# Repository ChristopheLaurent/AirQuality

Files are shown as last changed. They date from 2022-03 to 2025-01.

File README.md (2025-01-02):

# AirQuality

The purpose of this project is indoor air quality monitoring with affordable IoT devices. It covers all aspects of the problem, from sensors to data monitoring, including 3D modeling, electronics, communication protocols, data base and web front end.

## IoT Device

The device displays CO2 level with a smiley depending on the CO2 level, so it can be used in standalone mode.



The device is based on 2 circuits, connected via I2C in a [3D printed casing](https://github.com/ChristopheLaurent/AirQuality/tree/main/Model3D):
### [Sensirion SCD41](https://developer.sensirion.com/sensirion-products/scd4x-co2-sensors/)
The SEK-SCD41-Sensor Evaluation Kit can measure CO2 level, Humidity and Temperature. It is powered in 3.3V. The sampling rate is 5s in normal mode, 30s in low power mode.
### [LILYGO® TTGO T5 V2.3.1_2.13](https://lilygo.cc/products/t5-v2-3-1)
This [ESP32 ECO V3](https://www.espressif.com/sites/default/files/documentation/ESP32_ECO_V3_User_Guide__EN.pdf) module integrates an e-Paper screen, SD card, USB, JSP plug for battery support, WiFi and Bluetooth. The JST plug can be connected to an optional 18650 lithium battery. The USB can be connected to a 5V/1A mobile phone power supply.

## Backend server

The devices can connect to a Flask server via WiFi / MQTT.



The Flask server can run on a PC, together with a mosquitto broker and PostgreSQL data base

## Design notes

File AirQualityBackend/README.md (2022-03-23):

# Backend

AirQuality backend is designed to run on a local WiFi network, not the cloud. It handles MQTT publications from sensors south bound, and Web request from browsers north bound. It stores all measures from sensors on a local PostGres data base.



## Windows Installation steps

### PostgreSQL
- [Install postgres DB](https://www.postgresql.org/download/windows/)
- You can use `admin` as password. (it is hardcoded in the source code for the time being)
- Do not launch stack builder at exit.
- Create database `AirQuality` (using pgAdmin for example)

### Mosquitto
- [Install Mosquitto broker](https://mosquitto.org/download/)
- If you choose to run mosquitto as a service, you can reboot your computer then check mosquitto.exe process is running.
- If you decide to run it manually, go to the mosquitto folder with a command prompt then type `mosquitto -v`

### Python
- [Install latest Python 3 version](https://www.python.org/downloads/)
- During installation process, ticks Add Python 3.xx to PATH

Run as admin windows power shell then type the following commands:
-	`cd AirQuality\AirQualityBackend`
-	`Set-ExecutionPolicy Unrestricted -Force`
-	`pip install virtualenv`
-	`virtualenv venv`
-	`venv\Scripts\activate`
-	`pip install Flask`
-	`pip install psycopg2`
-	`pip install flask-mqtt`
-	`python init_db.py`
-	`$env:FLASK_APP = "app"`
-	`flask run --host=0.0.0.0`
-	Open your favorite browser then go to [http://127.0.0.1:5000/raw](http://127.0.0.1:5000/raw). You should see an empty table:



-	In another power shell, execute `python twin.py` . This will run a digital twin that simulates a sensor to populate the data base. If you refresh your browser, you should then see some data:



- You can then navigate up to the graphics:



## Data model

The data base is designed to support the following features:
- Each sensor is identified by its serial number.
- Each sensor has a type (for example SCD41, but it could be something else).
- Each sensor type has a set of channels.
- Each channel is defined by a name (for example CO2) and a unit (for example ppm).
- Each channel has a set of measures, e.g. samples (time stamp and value).
- At a given period of time, a sensor is in a location.
- A location is identified by a building, floor, room number...



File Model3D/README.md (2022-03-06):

# Hardware

Making Air Quality sensor only requires a 3D printer and basic soldering skills. The components are listed below:
- [SEK-SCD41-Sensor Evaluation Kit](https://developer.sensirion.com/sensirion-products/scd4x-co2-sensors/)
- [LILYGO® TTGO T5 V2.3.1_2.13](http://www.lilygo.cn/prod_view.aspx?TypeId=50061&Id=1393&FId=t3:50061:3)
- 11 x M2 screws 3mm
- [18650 battery holder](https://fr.aliexpress.com/item/1005001660193629.html) - optional
- 2 x magnets N35 10 x 3mm - optional
- 18650 lithium battery - optional

## 3D printing

The casing can be printed in PLA or PETG. It is designed for printing **without support**. *To be completed*

## Soldering
*To be completed*

## Connections
*To be completed*

## Assembling

- Slide the [button](https://github.com/ChristopheLaurent/AirQuality/blob/main/Model3D/button.stl) in the [main box](https://github.com/ChristopheLaurent/AirQuality/blob/main/Model3D/main.stl).
- Fasten the SCD41 kit and the micro controler in the main box with 8 M2 screws.
- Push the magnets in the holes of the [back](https://github.com/ChristopheLaurent/AirQuality/blob/main/Model3D/back.stl).
- Fasten the 18650 battery holder with 1 M2 screw.
- Insert the 18650 battery. **Double check polarity**.
- Fasten the back to the main box with 2 M2 screws.

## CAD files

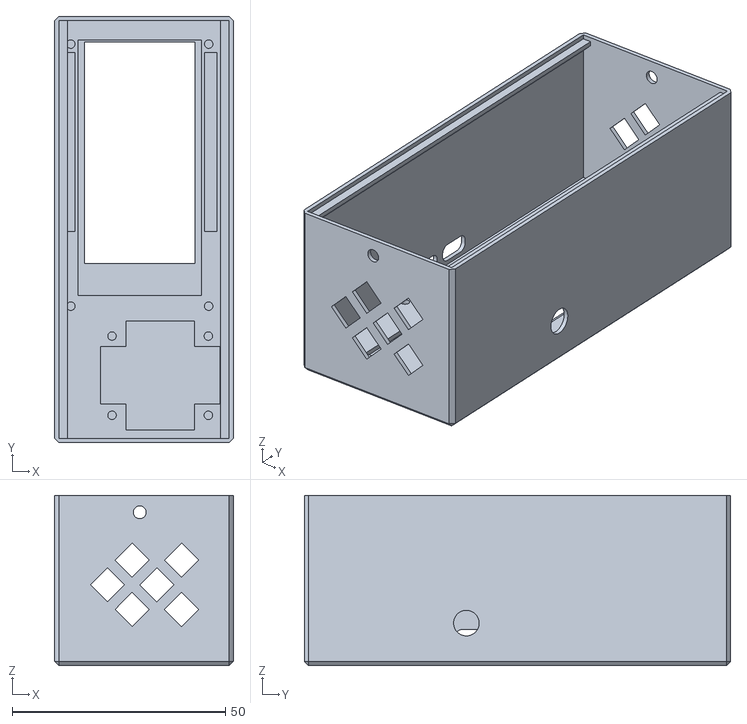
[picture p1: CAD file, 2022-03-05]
Model3D/main.stl
42.0 x 100.0 x 40.0

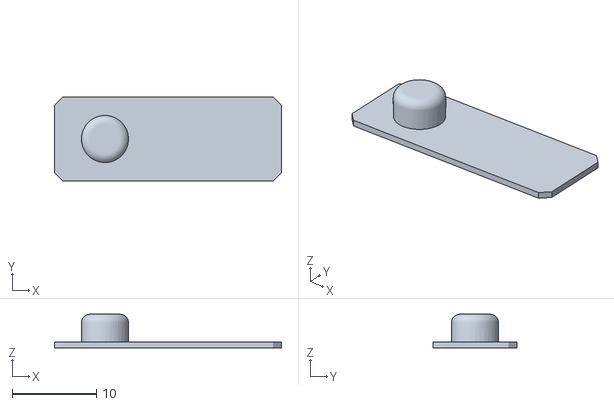
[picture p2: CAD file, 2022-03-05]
Model3D/button.stl
27.0 x 10.0 x 4.00

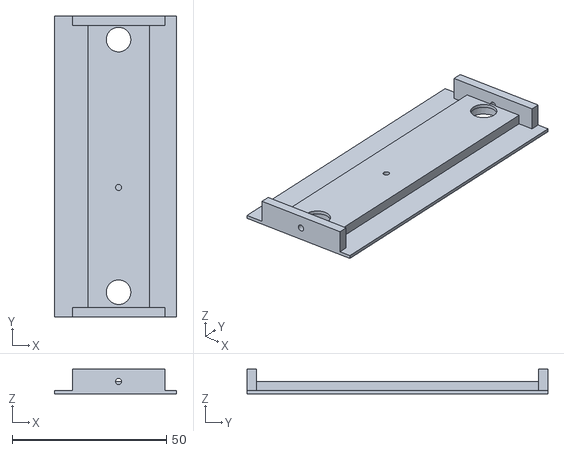
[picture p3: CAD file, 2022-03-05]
Model3D/back.stl
39.6 x 97.6 x 8.00

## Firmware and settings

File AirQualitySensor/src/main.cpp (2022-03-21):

// Air quality main source code

#include "Screen.h"
#include <Wire.h>
#include <WiFi.h>
#include "Sensor.h"
#include "Battery.h"
#include "MqttClient.h"
#include "SdCard.h"
#include <esp32fota.h>
#include "SPIFFS.h"
#include "TimeKeeper.h"
// #include <esp_arduino_version.h> // works from V2

#define BUTTON_1                (39) // pin for button1 used for wake up

#define CO2_WIFI_ENABLED 1           // 1 to enable WiFi

#define FIRMWARE_VERSION 6           // firmware version. should match AirQualityBackend/static/fota/version.h
const char* firmwareName = "AirQ";   // firmware name. should match AirQualityBackend/static/fota/version.h

esp_sleep_source_t wakeupReason;
RTC_DATA_ATTR int bootCount = 0;     // keep tracks of boot from wake up
RTC_DATA_ATTR int wifiConnectionFailures = 0; // keep track of wifi connection failures to avoid spending battery when no wifi
int loopCount = 0;

const char* formatDateTime = "%d %b %H:%M:%S";
TimeKeeper timeKeeper; // class to keep track of time
Screen ePaper; // class to handle GUI
Sensor sensor; // class to handle sensor
Battery battery; // class to handle battery monitoring
SdCard sdCard(&timeKeeper); // class to handle storage of measures on sd card
esp32FOTA esp32FOTA(String(firmwareName), FIRMWARE_VERSION, false);

// TODO: avoid hard coded WiFi & mosquitto credentials
const char* server = "http://192.168.1.108:5000/";
const char* ssid="TP-Link_CD96";
const char *password ="24232876";
const char *mqttBroker = "192.168.1.108";
const char *mqttUser = "";
const char *mqttPassword = "";
const int mqttPort = 1883;
MqttClient *mqttClient = NULL;
WiFiClient wifiClient;
PubSubClient pubSubClient(wifiClient);

// scan wifi access point for test purpose. Not used.
void testWiFi()
{
    WiFi.mode(WIFI_STA);
    WiFi.disconnect();
    // WiFi.scanNetworks will return the number of networks found
    int n = WiFi.scanNetworks();

    Serial.println("scan done");
    if (n == 0) {
        Serial.println("no networks found");
    } else {
        Serial.print(n);
        Serial.println(" networks found");
        for (int i = 0; i < n; ++i) {
            // Print SSID and RSSI for each network found
            Serial.print(i + 1);
            Serial.print(": ");
            Serial.print(WiFi.SSID(i));
            Serial.print(" (");
            Serial.print(WiFi.RSSI(i));
            Serial.print(")");
            Serial.println((WiFi.encryptionType(i) == WIFI_AUTH_OPEN) ? " " : "*");
            delay(10);
        }
    }
    Serial.println("");
}

// set the current time
int setTime(double timeStamp) // seconds since epoch including ms as decimals
{
  log_v("Got time %s", timeKeeper.toDate(timeStamp));
  timeKeeper.setTime(timeStamp);
  return 1;
}

// disbale Wifi when not needed to save battery
void disableWifi()
{
  // reduce power: https://www.mischianti.org/2021/03/06/esp32-practical-power-saving-manage-wifi-and-cpu-1/
      /*
        Note: at 80Mhz, no wifi, no bluetooth we have:
        - 26 mA without reading
        - 74 mA while reading every 5s
        with an average at 40 mA, a battery of 2800 mAh should last around 70h ~ 3 days

        at 80Mhz, one shot reading: noisy (variations +/- 200 ppm)
        - 25~75 mA while reading
        - 0.49 mA in hibernation with sensirion powered on
        - 0.29 mA in hibernation with sensition powered off

        at 80MHz, low power reading
        - 26 mA in refresh (~5s)
        - 2 mA ~ 50 mA while reading (~1s)
        - 0.94 mA between read
      */
  WiFi.disconnect(true); // Disconnect from the network
  WiFi.mode(WIFI_OFF);   // turn off wifi
}

// start Wifi/MQTT connection
void wifiConnection()
{
  WiFi.softAPdisconnect();
  WiFi.disconnect();
  WiFi.mode(WIFI_STA);
  delay(100);
  WiFi.begin(ssid, password);
  int i = 0;
  wl_status_t status = WL_IDLE_STATUS;
  for (i=0; i < 30 && status != WL_CONNECTED; i++)
  {
    delay(500);
    status = WiFi.status();
    log_d ("status = %d", status);
  }

  if (status == WL_CONNECTED)
  {
    String message = "connected to " + WiFi.localIP().toString();
    log_d("%s", message.c_str());
    ePaper.printMessage(message);

    log_d("Check firmware OTA");
    esp32FOTA.checkURL = String(server) + String("check_fota");
    bool updatedNeeded = esp32FOTA.execHTTPcheck();
    if (updatedNeeded)
    {
      log_d("Firmware OTA started...");
      ePaper.printMessage("OTA firmware update started, please wait");
      esp32FOTA.execOTA();
      // does not go any further since execOTA reboots
    }
    else
    {
      log_d("no need to update firmware");
    }
  }
  else
  {
    String message = "WiFi error " + String(status);
    wifiConnectionFailures++;
    ePaper.printMessage(message);
    disableWifi();
    return;
  }

  log_d("Init mqtt");
// TODO: handle TLS
  mqttClient = new MqttClient();

  mqttClient->setTimeCB = &(setTime);
  mqttClient->init(&pubSubClient, sensor.getSerial());
  mqttClient->setBrokerCredentials(mqttBroker, mqttPort, mqttUser, mqttPassword);
  mqttClient->publishAnouncement();
  log_d("mqtt initialized");
}

// Check chip id for test purpose.
void checkChip()
{
  esp_chip_info_t chip_info;

  esp_chip_info(&chip_info);
  log_v("This is ESP32 chip with %d CPU cores, WiFi%s%s, ",
            chip_info.cores,
            (chip_info.features & CHIP_FEATURE_BT) ? "/BT" : "",
            (chip_info.features & CHIP_FEATURE_BLE) ? "/BLE" : "");

  log_v("silicon revision %d, ", chip_info.revision);

  log_v("%dMB %s flash\n", spi_flash_get_chip_size() / (1024 * 1024),
            (chip_info.features & CHIP_FEATURE_EMB_FLASH) ? "embedded" : "external");

  uint8_t mac[6];
  char macString[13];
  esp_efuse_mac_get_default(mac);
  for (int i=0; i<6; i++) sprintf(macString+(2*i), "%02X", mac[i]);
  macString[12] = 0;
  log_v ("MAC: %s\n", macString);
}

// Go to deep sleep for a time.
void sleep(int seconds)
{
    ePaper.powerDown();
    sdCard.close();

    if (seconds <= 0)
    {
      log_d("sleep until button pressed");
      sensor.powerDown();
    }
    else
    {
      esp_sleep_enable_timer_wakeup(seconds * 1000 * 1000);
      log_d("sleep for %d seconds or until button pressed", seconds);
    }

    esp_sleep_enable_ext1_wakeup(((uint64_t)(((uint64_t)1) << BUTTON_1)), ESP_EXT1_WAKEUP_ALL_LOW);
    esp_deep_sleep_start();
}

// the startup function called once by Arduino on boot
void setup()
{
    Serial.begin(9600);
    log_d("setup");
    
    wakeupReason = esp_sleep_get_wakeup_cause();
    bootCount++;
    log_d("wakeup reason = %d, boot count = %d", wakeupReason, bootCount);

    log_v("ESP IDF %s", esp_get_idf_version());
#ifdef ESP_ARDUINO_VERSION_MAJOR // works from ESP32 Arduino V2. Still use 1.0.6 for the time being
    log_v("ESP_ARDUINO V%d.%d.%d", ESP_ARDUINO_VERSION_MAJOR, ESP_ARDUINO_VERSION_MINOR, ESP_ARDUINO_VERSION_PATCH);
#endif

    checkChip(); // for test purpose
    btStop();              // disconnect bluetooth
    setCpuFrequencyMhz(80); // good enough, save power and heat...

    log_d("%d samples left in sensor stack", sensor.stackSpace()); // this does not require sensor.init() that takes time
    bool needWifi = false;
#ifdef CO2_WIFI_ENABLED
    needWifi = (wakeupReason != ESP_SLEEP_WAKEUP_TIMER || 
                (sensor.stackSpace() < 3 && wifiConnectionFailures < 3));
#endif
    if (!needWifi)
    {
      disableWifi();  // disable wifi asap, prior time consuming initializations...
    }

    bool spiffOk = SPIFFS.begin();
    if (!spiffOk)
    {
      log_v("Formatting spiff...");
      if (SPIFFS.format())
      {
        spiffOk =  SPIFFS.begin();
      }
    }

    Wire.begin();
    ePaper.init();

    int sensorMode = (wakeupReason == ESP_SLEEP_WAKEUP_TIMER) ? SENSOR_LOW_POWER : SENSOR_NORMAL;
    log_d ("sensor mode = %d", sensorMode);

    if (! sensor.init(sensorMode))
    {
      log_e("%s", sensor.getErrorMessage().c_str());
    }

    ePaper.info1 = String(firmwareName) + " V" + String(FIRMWARE_VERSION) + " - SCD41";
    ePaper.info2 = String(timeKeeper.toDate(timeKeeper.now(), formatDateTime));
    battery.init();
    sdCard.init(String(sensor.getSerial()), wakeupReason != ESP_SLEEP_WAKEUP_TIMER);

    if (needWifi)
    {
      // mqttClient = new MqttClient();
      wifiConnection(); // this requires prior initializations of screen and sensor for serial number
    }
}

// the loop function called forever by Arduino framework after setup
void loop()
{
  battery.measure();
  ePaper.bat = battery.load;

  double now = timeKeeper.now();
  ePaper.info2 = String(timeKeeper.toDate(now, formatDateTime));
  if (sensor.measure(now))
  {
    log_i("%d ,\t%f ,\t%f", (int)sensor.last.co2, sensor.last.temperature, sensor.last.humidity);

    ePaper.co2 = sensor.last.co2;
    ePaper.temp = sensor.last.temperature;
    ePaper.h2o = sensor.last.humidity;
  }
  else
  {
    log_e("%s", sensor.getErrorMessage().c_str());
  }

  ePaper.printLevels();

  if (mqttClient != NULL) 
  {
    for (int i=0; i<30 && !mqttClient->loop(); i++)
    {
      log_d("wait for MQTT (%ds)", i);
      delay(1000);
    }

    if (mqttClient->loop())
    {
      mqttClient->publishMonitoring(battery.voltage, battery.load);
      int numMeasures = 0;
      struct Measure *measures = sensor.getStack(&numMeasures);
      log_d("%d measures to send", numMeasures);
      for (int i=0; i<numMeasures; i++)
      {
        mqttClient->publishMeasure(measures->timeStamp, measures->co2, measures->temperature, measures->humidity);
        mqttClient->loop();
        measures++;
      }
      delay(100); // give more time to mqtt, not sure if this is needed...
    }
  }

  sdCard.appendRecord(sensor.last.co2, sensor.last.temperature, sensor.last.humidity, battery.voltage);

  int bat0 = 0;
  while (battery.load == 0)
  {
    log_i("voltage = %fV, load = %d%%\n", battery.voltage, battery.load);

    if (bat0++ < 3)
    {
      delay(100);
    }
    else
    {
      sleep(-1);
    }

    battery.measure();
  }

  if (sensor.getMode() == SENSOR_LOW_POWER)
  {
    sleep(60); 
    // we do not got continue beyond this point since sleep with ends up in setup 1 min later
  }

  if (sensor.getMode() == SENSOR_NORMAL && loopCount > 10)
  {
    sensor.changeMode(SENSOR_LOW_POWER);
  }

  loopCount++;
  delay(5000); // wait 5 s since in normal mode, we get a measure every 5 s.
}

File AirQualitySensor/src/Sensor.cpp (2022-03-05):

#include <SPIFFS.h>
#include "Sensor.h"

#include <SensirionI2CScd4x.h>
#define STACK_CAPACITY 50

SensirionI2CScd4x scd4x;
RTC_DATA_ATTR int stackIndex = 0;
RTC_DATA_ATTR struct Measure stack[STACK_CAPACITY];

Sensor::Sensor()
{
}

void Sensor::powerDown()
{
  scd4x.powerDown();
}

bool Sensor::init(int mode)
{
  Wire.beginTransmission(0x62);
  uint8_t status = Wire.endTransmission();
  if (status == 0)
  {
    _mode = mode;
  }
  else
  {
    sprintf(_errorMessage, "Sensor not responding, wire error code = %d", status);
    log_e("%s", _errorMessage);
    _mode = SENSOR_MOCKUP;
  }

  if (_mode == SENSOR_MOCKUP)
  {
    strcpy(_serial, "MOCK");
    uint8_t mac[6];
    esp_efuse_mac_get_default(mac);
    for (int i=2; i<6; i++) sprintf(_serial+(2*i), "%02X", mac[i]);
    return true;
  }

  scd4x.begin(Wire);
  uint16_t dataReady = false;

  if (_mode == SENSOR_NORMAL)
  {
    // In high power mode, we call init only once but we don't know if the
    // sensor was in low power (measurement every 30s) or high power (measurement every 5s)
    // mode. So it is just safer to stop periodic measurement and restart it.
    scd4x.stopPeriodicMeasurement();
  }
  else
  {
    // In low power mode, we are in a cycle of power on / power off
    // but sensor needs to be initialized only for the very first power on.
    // In the case of very first power on, the sensor has never been initialized
    // so dataReady from getDataReadyStatus() should be false
    // hence we can perform initialization. 
    _error = scd4x.getDataReadyStatus(dataReady);
    if (_error)
    {
      strcpy(_errorMessage, "Error in getDataReadyStatus()");
      return false;
    }
  }

  if (dataReady)
  {
    // we know 2 things: We are in low power mode and this is not the very first
    // initialisation, so we should find the serial number from SPIFF
    File file = SPIFFS.open(F("/serial.txt"), "r");
    if (file)
    {
      size_t size = file.readBytesUntil('\n', _serial, sizeof(_serial)-1);
      _serial[size] = '\0';
      if (size != sizeof(_serial)-1)
      {
        sprintf(_errorMessage, "Wrong serial number from SPIFF = %s", _serial);
        return false;
      }
    }
    else
    {
      strcpy(_errorMessage, "File serial.txt missing on SPIFF => no serial number");
      strcpy(_serial, "XXXXXXXXXXXX");
      return false;
    }
  }
  else
  {
    // This is the very first initialization, get serial number and save it.
    uint16_t serial[3];
    _error = scd4x.getSerialNumber(serial[0], serial[1], serial[2]);
    if (_error)
    {
      strcpy(_errorMessage, "Error in getSerialNumber()");
      return false;
    }

    sprintf(_serial, "%04X%04X%04X", serial[0], serial[1], serial[2]);
    log_d ("initialization, serial number = %s\n", _serial);

    File file = SPIFFS.open(F("/serial.txt"), "w");
    if (file)
    {
        file.printf("%s\n", _serial);
        file.flush();
        file.close();
    }
    else
    {
      log_e ("unable to write serial on SPIFF");
    }

    if (_mode == SENSOR_LOW_POWER)
    {
      log_d("start low power periodic measurement every 30s");
      _error = scd4x.startLowPowerPeriodicMeasurement();
    }
    else
    {
      log_d("start periodic measurement every 5s");
      _error = scd4x.startPeriodicMeasurement();
    }

    if (_error)
    {
      strcpy(_errorMessage, "Error in startPeriodicMeasurement()");
      return false;
    }

    log_d("Waiting for data ready");
    for (int i=0; i < 60 && !dataReady; i++)
    {
      log_d("%d",i);
      _error = scd4x.getDataReadyStatus(dataReady);
      if (_error)
      {
        strcpy(_errorMessage, "Error in getDataReadyStatus()");
        return false;
      }
      delay(1000);
    }
    log_i("CO2 [ppm], Temp [degC], Humidity [%]");
  }
  return true;
}

void Sensor::changeMode(int mode)
{
  if (_mode != SENSOR_MOCKUP)
  {
    scd4x.stopPeriodicMeasurement();
    
    if (mode == SENSOR_LOW_POWER)
    {
      log_d("start low power periodic measurement every 30s");
      _error = scd4x.startLowPowerPeriodicMeasurement();
    }
    else
    {
      log_d("start periodic measurement every 5s");
      _error = scd4x.startPeriodicMeasurement();
    }

    if (!_error)
    {
      _mode = mode;
    }
  }
}

bool Sensor::measure(double timeStamp)
{
  last.timeStamp = timeStamp;

  if (_mode == SENSOR_MOCKUP)
  {
    int seed = (int)millis();
    last.co2 = (seed / 300) % 1500;
    last.temperature = (seed / 10000) % 30;
    last.humidity = (seed / 2000) % 100;
    push();
    return true;
  }

  _error = scd4x.readMeasurement(last.co2, last.temperature, last.humidity);
  if (_error)
  {
    strcpy(_errorMessage, "Error in readMeasurement()");
    return false;
  }
  else if (last.co2 == 0)
  {
    strcpy(_errorMessage, "Invalid sample detected, skipping.");
    return false;
  }

  push();
  return true;
}

void Sensor::push()
{
  if (stackIndex < STACK_CAPACITY)
  {
    stack[stackIndex++] = last;
    log_v("%d measures pushed to stack", stackIndex);
  }
  else
  {
    log_e("cannot stack more measures");
  }
}

int Sensor::stackSpace()
{
  return STACK_CAPACITY - stackIndex;
}

Measure* Sensor::getStack(int *numMeasures)
{
  *numMeasures = stackIndex;
  stackIndex = 0;
  return stack;
}

int Sensor::getMode()
{
  return _mode;
}

char* Sensor::getSerial()
{
  return _serial;
}

String Sensor::getErrorMessage()
{
  String str1 = String(_errorMessage);
  String str2 = ": ";
  errorToString(_error, _errorMessage, 256);
  String str3 = String(_errorMessage);
  return str1 + str2 + str3;
}

void scanI2c() {
  byte error, address;
  int nDevices;
  nDevices = 0;
  for (address = 1; address < 127; address++)
  {
    Wire.beginTransmission(address);
    error = Wire.endTransmission();
    if (error == 0)
    {
      String msg = String("I2C device found at address 0x");
      if (address < 16) msg += "0";
      msg += String(address, HEX);
      Serial.println(msg);
      nDevices++;
    }
    else if (error == 4)
    {
      String msg = String("Unknow error at address 0x");
      if (address < 16) msg += "0";
      msg += String(address, HEX);
      Serial.println(msg);
    }
  }
  if (nDevices == 0)
  {
    Serial.println("No I2C devices found");
  }
}

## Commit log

2022-03-05 release 3D model
    [back.stl, button.stl, main.stl]
2022-03-21 Add comments to sensor code
    Add comments to sensor code
